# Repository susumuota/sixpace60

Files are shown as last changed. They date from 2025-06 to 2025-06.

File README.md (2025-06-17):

# Infinite Monkey Sixpace60

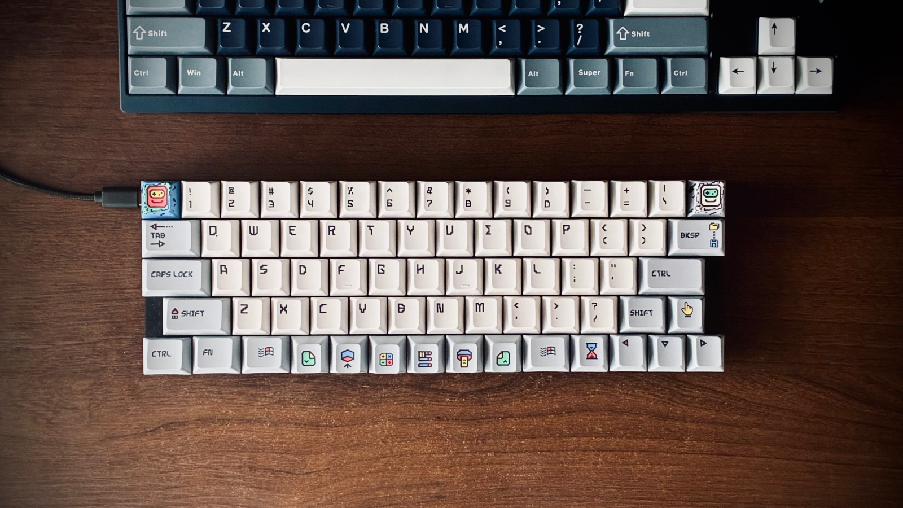
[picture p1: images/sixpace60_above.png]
Infinite Monkey Sixpace60


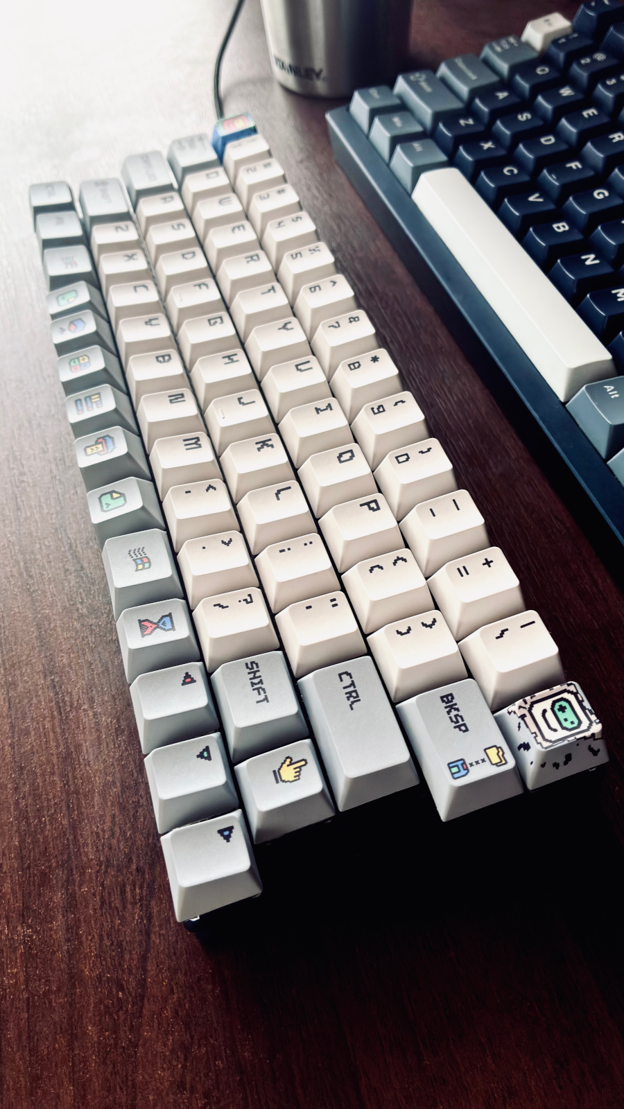
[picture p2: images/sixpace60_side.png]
Infinite Monkey Sixpace60


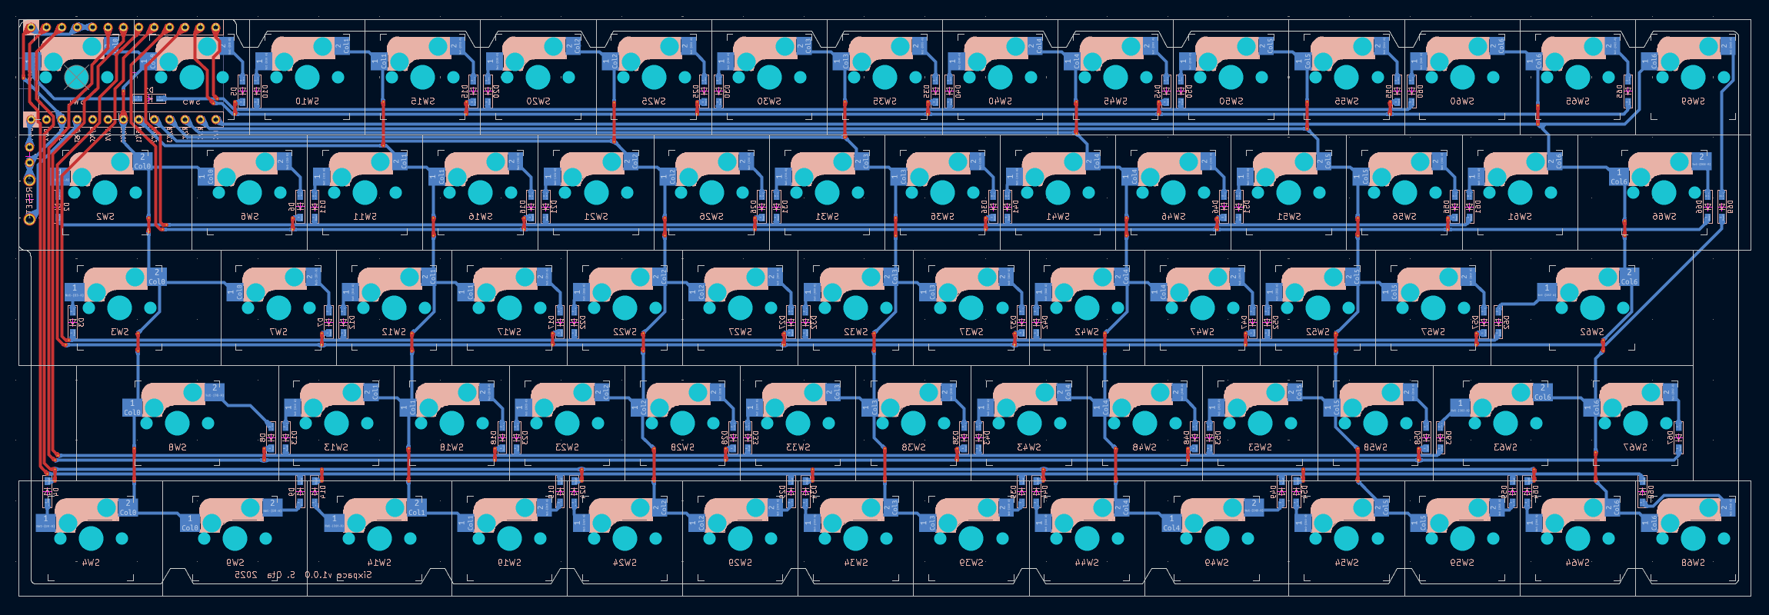
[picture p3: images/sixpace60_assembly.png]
Infinite Monkey Sixpace60


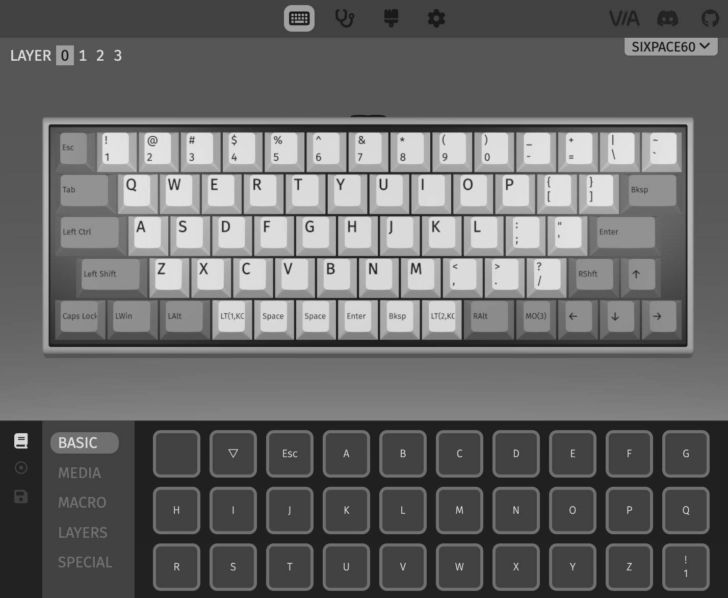
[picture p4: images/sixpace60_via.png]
Infinite Monkey Sixpace60


- Based on 60% layout
- Six space keys
- Arrow keys
- No stabilizers
- Supports [VIA](https://caniusevia.com/), [Remap](https://remap-keys.app/) and [VIAL](https://get.vial.today/)

## Installation

- Install [QMK Toolbox](https://qmk.fm/toolbox) to flash the firmware
- Open the QMK Toolbox
- Connect your keyboard
- Press `Open` and select the firmware file [firmware/infinitemonkey_sixpace60_via.hex](firmware/infinitemonkey_sixpace60_via.hex) for VIA or [firmware/infinitemonkey_sixpace60_vial.hex](firmware/infinitemonkey_sixpace60_vial.hex) for VIAL
- Press the reset button on your keyboard **twice quickly** to put it into bootloader mode
- Press `Flash` in the QMK Toolbox

## Setting Up with VIA

- Go to [VIA](https://www.usevia.app/)
- Press `SETTINGS` and turn on `Show Design tab`
- Press `DESIGN`, press `Load`, and select [qmk/keyboards/infinitemonkey/sixpace60/via.json](qmk/keyboards/infinitemonkey/sixpace60/via.json)
- Press `CONFIGURE` press `Authorize device +` and select `Sixpace60`

## Setting Up with VIAL

- Go to [Vial Web](https://vial.rocks/)
- Press `Start Vial`
- Select `Sixpace60`

## Building the Firmware

Install [Docker](https://www.docker.com/get-started) to build the firmware.

### Build for VIA and Remap

```shell
git clone https://github.com/qmk/qmk_firmware.git
git clone https://github.com/susumuota/sixpace60.git
cp -rp sixpace60/qmk/keyboards/infinitemonkey qmk_firmware/keyboards
cd qmk_firmware
RUNTIME="docker" SKIP_FLASHING_SUPPORT=1 util/docker_cmd.sh make infinitemonkey/sixpace60:via
```

### Build for VIAL

```shell
git clone https://github.com/vial-kb/vial-qmk.git
git clone https://github.com/susumuota/sixpace60.git
cp -rp sixpace60/qmk/keyboards/infinitemonkey vial-qmk/keyboards
cd vial-qmk
RUNTIME="docker" SKIP_FLASHING_SUPPORT=1 util/docker_cmd.sh make infinitemonkey/sixpace60:vial
```

## License

This project is licensed under the MIT License - see the [LICENSE](LICENSE) file for details.

## Author

- [Susumu OTA](https://github.com/susumuota)

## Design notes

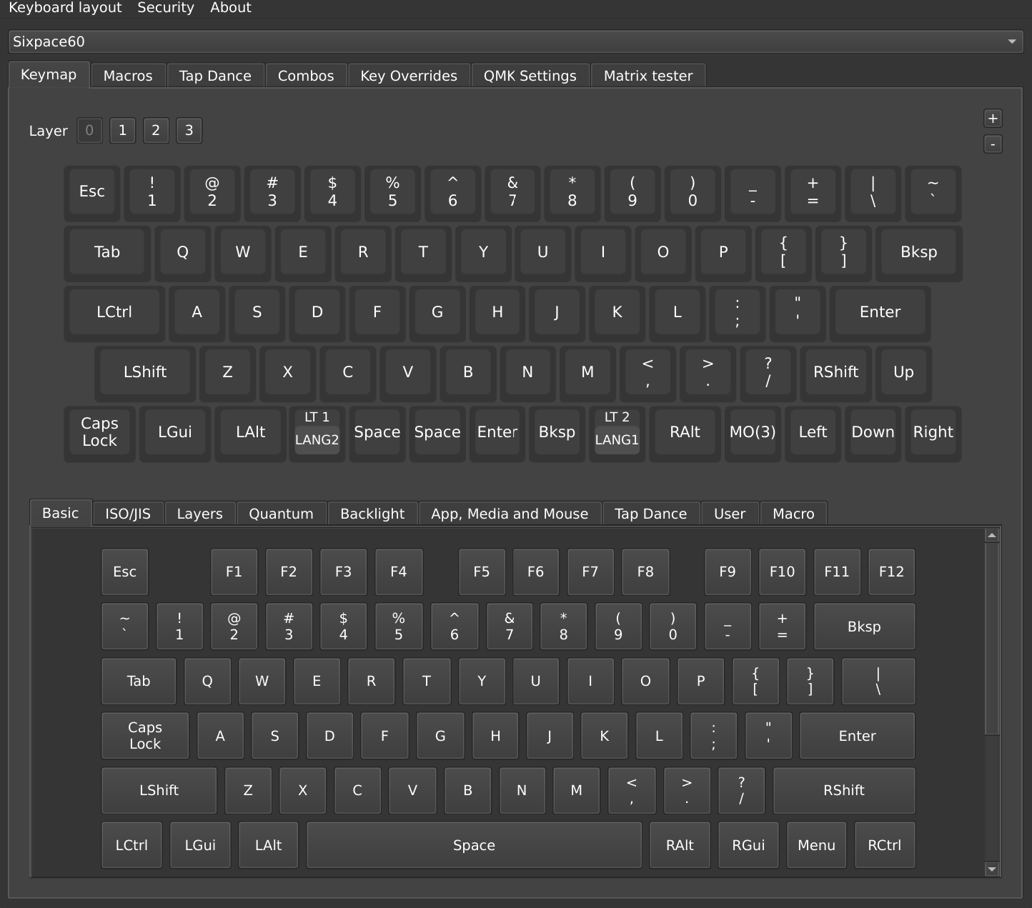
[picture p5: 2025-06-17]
images/sixpace60_vial.png

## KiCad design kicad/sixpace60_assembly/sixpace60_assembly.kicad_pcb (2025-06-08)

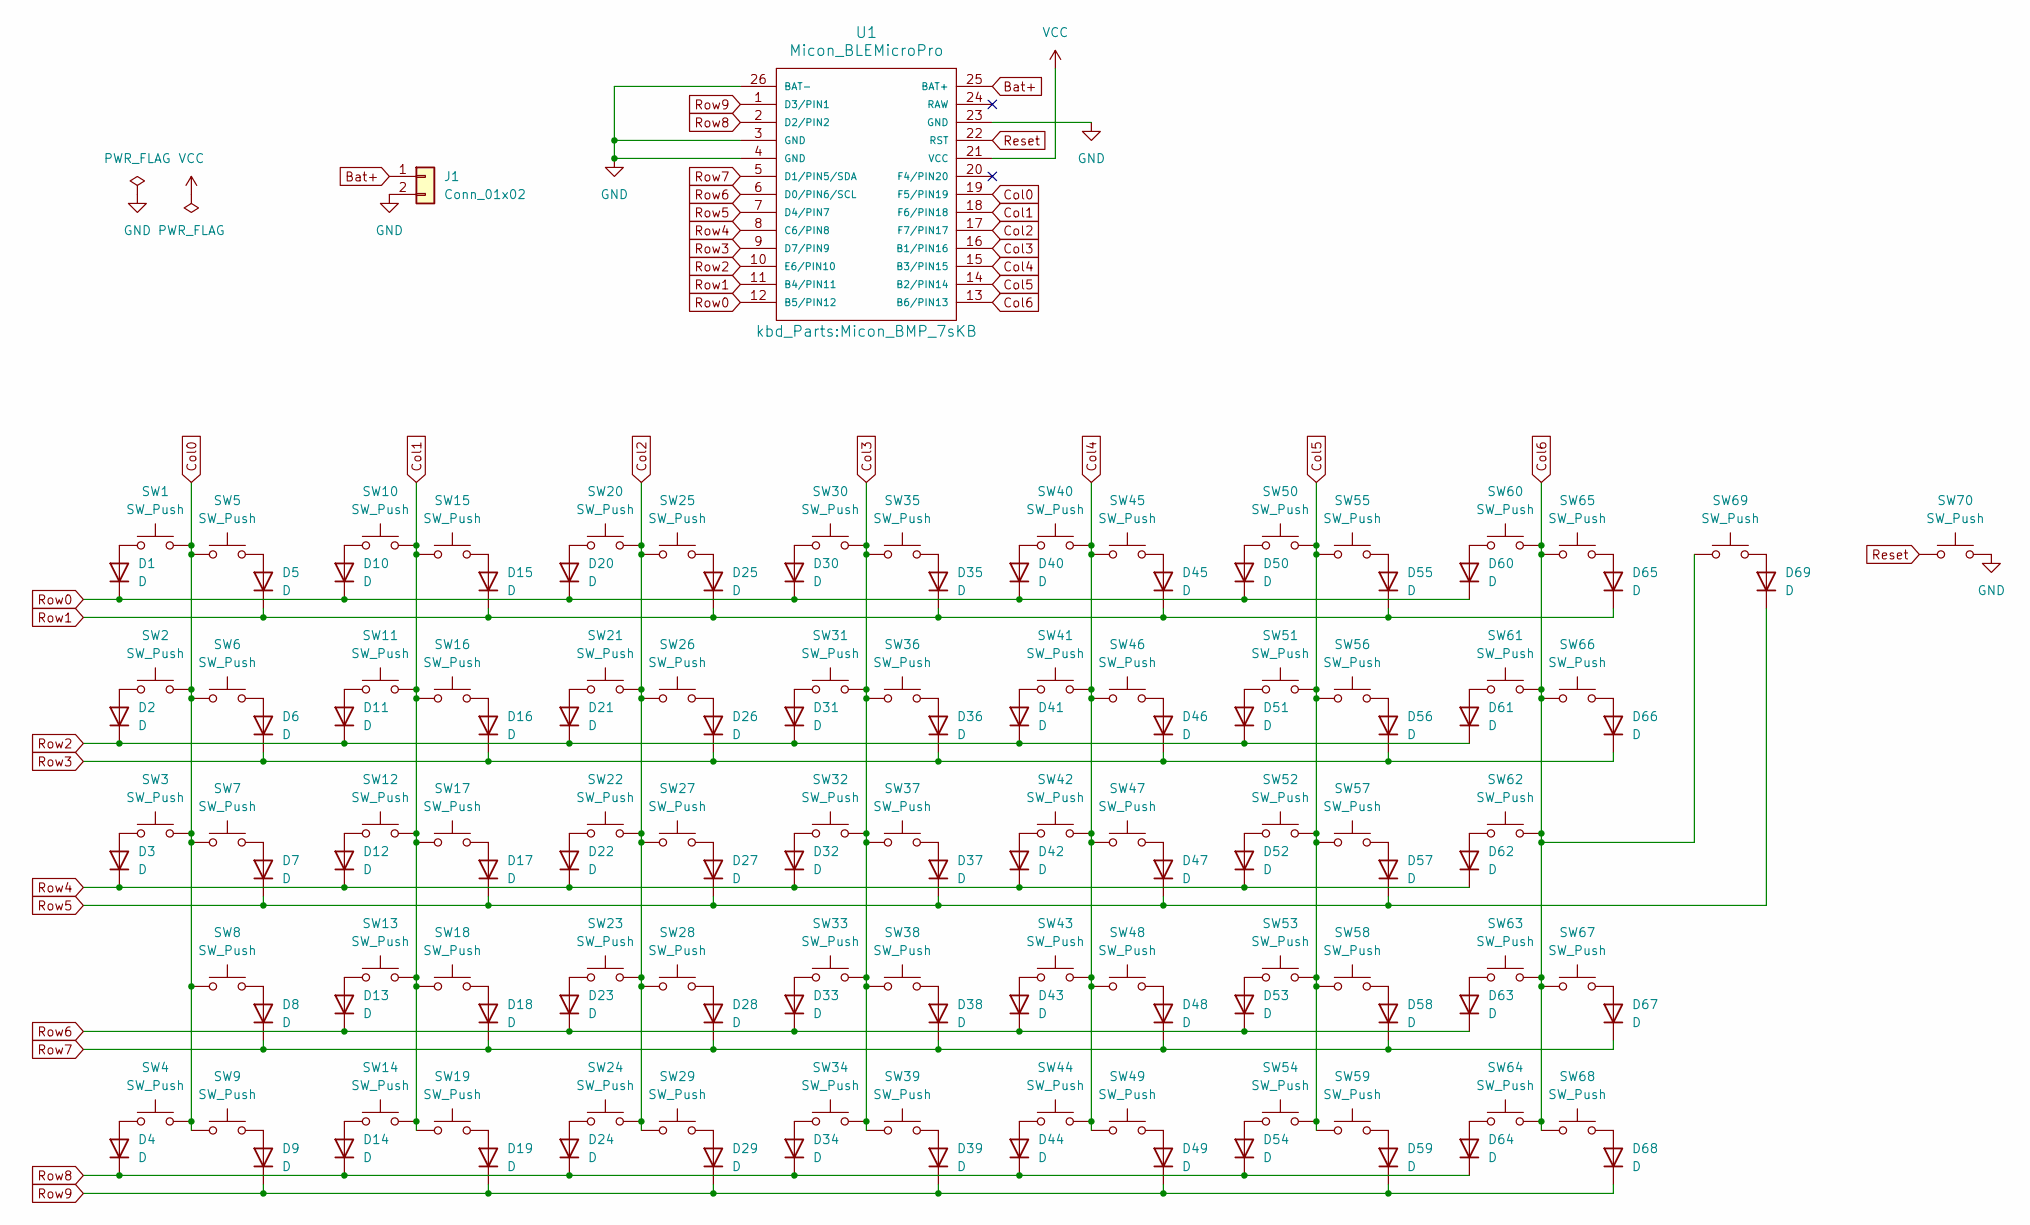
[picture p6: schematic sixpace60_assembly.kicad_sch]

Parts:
D1, D2, D3, D4, D5, D6, D7, D8, D9, D10, D11, D12, D13, D14, D15, D16, D17, D18, D19, D20, D21, D22, D23, D24, D25, D26, D27, D28, D29, D30, D31, D32, D33, D34, D35, D36, D37, D38, D39, D40, D41, D42, D43, D44, D45, D46, D47, D48, D49, D50, D51, D52, D53, D54, D55, D56, D57, D58, D59, D60, D61, D62, D63, D64, D65, D66, D67, D68, D69: D; Diode_SMD
J1: Conn_01x02; Battery_BMP_2pin
SW1, SW5, SW6, SW7, SW10, SW11, SW12, SW13, SW15, SW16, SW17, SW18, SW19, SW20, SW21, SW22, SW23, SW24, SW25, SW26, SW27, SW28, SW29, SW30, SW31, SW32, SW33, SW34, SW35, SW36, SW37, SW38, SW39, SW40, SW41, SW42, SW43, SW44, SW45, SW46, SW47, SW48, SW50, SW51, SW52, SW53, SW54, SW55, SW56, SW57, SW58, SW59, SW60, SW61, SW64, SW65, SW67, SW68, SW69: SW_Push; CherryMX_Hotswap_1u_Small3
SW2, SW66: SW_Push; CherryMX_Hotswap_1.5u
SW3, SW8, SW62: SW_Push; CherryMX_Hotswap_1.75u
SW4, SW9, SW14, SW49, SW63: SW_Push; CherryMX_Hotswap_1.25u
SW70: SW_Push; ResetSW
U1: Micon_BLEMicroPro; Micon_BMP_7sKB

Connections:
Bat+: J1.1, U1.25 (BAT+)
Col0: SW1.2, SW2.2, SW3.2, SW4.2, SW5.1, SW6.1, SW7.1, SW8.1, SW9.1, U1.19 (F5/PIN19)
Col1: SW10.2, SW11.2, SW12.2, SW13.2, SW14.2, SW15.1, SW16.1, SW17.1, SW18.1, SW19.1, U1.18 (F6/PIN18)
Col2: SW20.2, SW21.2, SW22.2, SW23.2, SW24.2, SW25.1, SW26.1, SW27.1, SW28.1, SW29.1, U1.17 (F7/PIN17)
Col3: SW30.2, SW31.2, SW32.2, SW33.2, SW34.2, SW35.1, SW36.1, SW37.1, SW38.1, SW39.1, U1.16 (B1/PIN16)
Col4: SW40.2, SW41.2, SW42.2, SW43.2, SW44.2, SW45.1, SW46.1, SW47.1, SW48.1, SW49.1, U1.15 (B3/PIN15)
Col5: SW50.2, SW51.2, SW52.2, SW53.2, SW54.2, SW55.1, SW56.1, SW57.1, SW58.1, SW59.1, U1.14 (B2/PIN14)
Col6: SW60.2, SW61.2, SW62.2, SW63.2, SW64.2, SW65.1, SW66.1, SW67.1, SW68.1, SW69.1, U1.13 (B6/PIN13)
GND: J1.2, SW70.2, U1.3 (GND), U1.4 (GND), U1.23 (GND), U1.26 (BAT-)
unnamed: D1.2 (A), SW1.1
unnamed: D2.2 (A), SW2.1
unnamed: D3.2 (A), SW3.1
unnamed: D4.2 (A), SW4.1
unnamed: D5.2 (A), SW5.2
unnamed: D6.2 (A), SW6.2
unnamed: D7.2 (A), SW7.2
unnamed: D8.2 (A), SW8.2
unnamed: D9.2 (A), SW9.2
unnamed: D10.2 (A), SW10.1
unnamed: D11.2 (A), SW11.1
unnamed: D12.2 (A), SW12.1
unnamed: D13.2 (A), SW13.1
unnamed: D14.2 (A), SW14.1
unnamed: D15.2 (A), SW15.2
unnamed: D16.2 (A), SW16.2
unnamed: D17.2 (A), SW17.2
unnamed: D18.2 (A), SW18.2
unnamed: D19.2 (A), SW19.2
unnamed: D20.2 (A), SW20.1
unnamed: D21.2 (A), SW21.1
unnamed: D22.2 (A), SW22.1
unnamed: D23.2 (A), SW23.1
unnamed: D24.2 (A), SW24.1
unnamed: D25.2 (A), SW25.2
unnamed: D26.2 (A), SW26.2
unnamed: D27.2 (A), SW27.2
unnamed: D28.2 (A), SW28.2
unnamed: D29.2 (A), SW29.2
unnamed: D30.2 (A), SW30.1
unnamed: D31.2 (A), SW31.1
unnamed: D32.2 (A), SW32.1
unnamed: D33.2 (A), SW33.1
unnamed: D34.2 (A), SW34.1
unnamed: D35.2 (A), SW35.2
unnamed: D36.2 (A), SW36.2
unnamed: D37.2 (A), SW37.2
unnamed: D38.2 (A), SW38.2
unnamed: D39.2 (A), SW39.2
unnamed: D40.2 (A), SW40.1
unnamed: D41.2 (A), SW41.1
unnamed: D42.2 (A), SW42.1
unnamed: D43.2 (A), SW43.1
unnamed: D44.2 (A), SW44.1
unnamed: D45.2 (A), SW45.2
unnamed: D46.2 (A), SW46.2
unnamed: D47.2 (A), SW47.2
unnamed: D48.2 (A), SW48.2
unnamed: D49.2 (A), SW49.2
unnamed: D50.2 (A), SW50.1
unnamed: D51.2 (A), SW51.1
unnamed: D52.2 (A), SW52.1
unnamed: D53.2 (A), SW53.1
unnamed: D54.2 (A), SW54.1
unnamed: D55.2 (A), SW55.2
unnamed: D56.2 (A), SW56.2
unnamed: D57.2 (A), SW57.2
unnamed: D58.2 (A), SW58.2
unnamed: D59.2 (A), SW59.2
unnamed: D60.2 (A), SW60.1
unnamed: D61.2 (A), SW61.1
unnamed: D62.2 (A), SW62.1
unnamed: D63.2 (A), SW63.1
unnamed: D64.2 (A), SW64.1
unnamed: D65.2 (A), SW65.2
unnamed: D66.2 (A), SW66.2
unnamed: D67.2 (A), SW67.2
unnamed: D68.2 (A), SW68.2
unnamed: D69.2 (A), SW69.2
Reset: SW70.1, U1.22 (RST)
Row0: D1.1 (K), D10.1 (K), D20.1 (K), D30.1 (K), D40.1 (K), D50.1 (K), D60.1 (K), U1.12 (B5/PIN12)
Row1: D5.1 (K), D15.1 (K), D25.1 (K), D35.1 (K), D45.1 (K), D55.1 (K), D65.1 (K), U1.11 (B4/PIN11)
Row2: D2.1 (K), D11.1 (K), D21.1 (K), D31.1 (K), D41.1 (K), D51.1 (K), D61.1 (K), U1.10 (E6/PIN10)
Row3: D6.1 (K), D16.1 (K), D26.1 (K), D36.1 (K), D46.1 (K), D56.1 (K), D66.1 (K), U1.9 (D7/PIN9)
Row4: D3.1 (K), D12.1 (K), D22.1 (K), D32.1 (K), D42.1 (K), D52.1 (K), D62.1 (K), U1.8 (C6/PIN8)
Row5: D7.1 (K), D17.1 (K), D27.1 (K), D37.1 (K), D47.1 (K), D57.1 (K), D69.1 (K), U1.7 (D4/PIN7)
Row6: D13.1 (K), D23.1 (K), D33.1 (K), D43.1 (K), D53.1 (K), D63.1 (K), U1.6 (D0/PIN6/SCL)
Row7: D8.1 (K), D18.1 (K), D28.1 (K), D38.1 (K), D48.1 (K), D58.1 (K), D67.1 (K), U1.5 (D1/PIN5/SDA)
Row8: D4.1 (K), D14.1 (K), D24.1 (K), D34.1 (K), D44.1 (K), D54.1 (K), D64.1 (K), U1.2 (D2/PIN2)
Row9: D9.1 (K), D19.1 (K), D29.1 (K), D39.1 (K), D49.1 (K), D59.1 (K), D68.1 (K), U1.1 (D3/PIN1)
VCC: U1.21 (VCC)

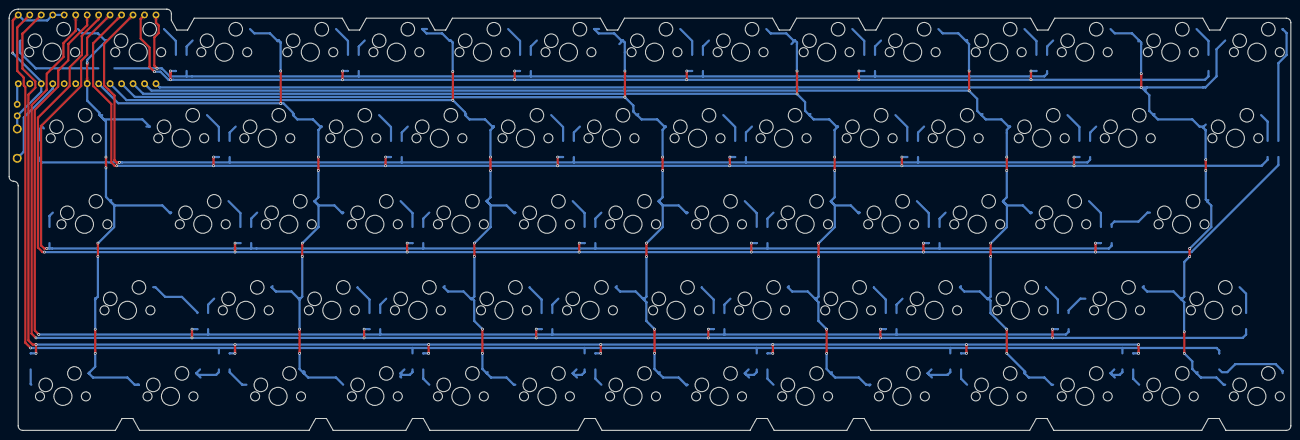
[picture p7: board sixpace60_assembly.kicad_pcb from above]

Board: 2 copper layers, 283.8 x 93.3 mm, 141 parts (1 on the bottom side), 89 nets.
